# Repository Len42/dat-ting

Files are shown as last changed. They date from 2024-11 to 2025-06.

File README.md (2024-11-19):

# dat ting

_Multi-function Eurorack module inspired by [dis ting](https://www.expert-sleepers.co.uk/disting.html)_

**dat ting** is a digital multi-function 10 HP Eurorack module using a [Daisy Seed](https://electro-smith.com/products/daisy-seed). Part of my [homebrew Eurorack synthesizer](https://lenp.net/synth/).

[See here](https://lenp.net/synth/dat-ting/) for more info.

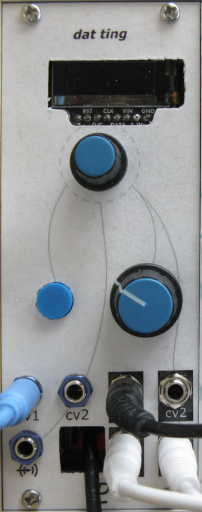
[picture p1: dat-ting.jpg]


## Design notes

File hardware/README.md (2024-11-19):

# dat ting

**dat ting** is a digital multi-function 10 HP Eurorack module using a [Daisy Seed](https://electro-smith.com/products/daisy-seed).

[See here](https://lenp.net/synth/dat-ting/hardware.html) for more info.

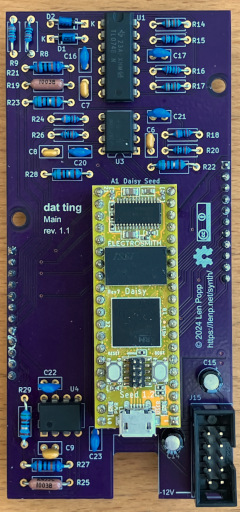
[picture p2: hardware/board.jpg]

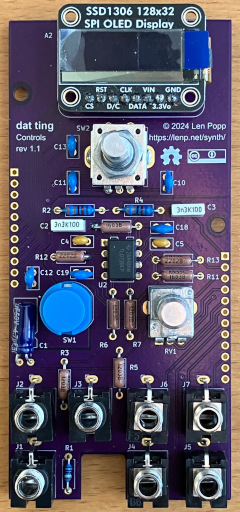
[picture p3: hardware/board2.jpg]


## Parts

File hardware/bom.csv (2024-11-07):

Reference | Qty | Value | Value2 | Note | Description | Datasheet | Manufacturer | ManufacturerPartNum | Distributor | DistributorPartNum | DistributorPartLink | Distributor2 | DistributorPartNum2 | DistributorPartLink2 | Distributor3 | DistributorPartNum3 | DistributorPartLink3
A1 | 1 | Daisy_Seed |  |  | Electrosmith Daisy Seed DSP Microcontroller Module ARM Cortex-M7 | https://daisy.nyc3.cdn.digitaloceanspaces.com/products/seed/Daisy_Seed_datasheet.pdf | Electrosmith |  | Electrosmith |  | https://electro-smith.com/products/daisy-seed | Thonk | PCB_Daisy_Seed | https://www.thonk.co.uk/shop/electrosmith-daisy-seed/
A2 | 1 | OLED_SPI_128x32 |  |  | OLED display module 128x32 pixels SPI with header | https://learn.adafruit.com/monochrome-oled-breakouts | Adafruit | 661 | Adafruit | 661 | https://www.adafruit.com/product/661
A3 | 1 | Cable_Eurorack_10 |  | Length as required | Eurorack 16-10 pin power cable |  |  |  | Thonk |  | https://www.thonk.co.uk/shop/eurorack-power-cables/ | SynthCube |  | https://synthcube.com/cart/eurorack-ribbon-power-cables | Modular Addict |  | https://modularaddict.com/parts/eurorack-power-cables-1
A4 | 1 | Micro USB Adapter 90deg |  |  | Micro USB adapter/cable, 90 deg. |  | StarTech |  | Amazon |  | https://www.amazon.ca/dp/B00EANUQ5M
C1 | 1 | 4U7 |  |  | Capacitor - Non-polarized Electrolytic | https://www.mouser.ca/datasheet/2/315/ABA0000C1053-947510.pdf | Panasonic | ECE-A1HN4R7U | Mouser | 667-ECE-A1HN4R7U | https://www.mouser.ca/ProductDetail/667-ECE-A1HN4R7U
C2 C3 | 2 | 3N3 |  |  | Capacitor - Film | https://www.mouser.ca/datasheet/2/447/KEM_F3101_R82-3316969.pdf | KEMET | R82EC1330AA50K | Mouser | 80-R82EC1330AA50K | https://www.mouser.ca/ProductDetail/KEMET/R82EC1330AA50K?qs=Jv4FAWB%252B0HZwlJiQ4ts8bA%3D%3D
C4 C5 | 2 | 5P6 | C0G/NP0 |  | Capacitor - Ceramic | https://www.mouser.ca/datasheet/2/212/KEM_C1049_GOLDMAX_C0G-1102120.pdf | KEMET | C315C569D1G5TA | Mouser | 80-C315C569D1G | https://www.mouser.ca/ProductDetail/?qs=qe%2F8UmbcoTBh6wC284cfAA%3D%3D
C6 C7 C8 C9 | 4 | 47P | C0G/NP0 |  | Capacitor - Ceramic | https://www.vishay.com/docs/45171/kseries.pdf | Vishay | K470K15C0GH53L2 | Mouser | 594-K470K15C0GH53L2 | https://www.mouser.ca/ProductDetail/Vishay-BC-Components/K470K15C0GH53L2?qs=vmM6vcLFxxH%252BnUnXm2ihfA%3D%3D
C10 C11 C12 C13 C16 C17 C18 C19 C20 C21 C22 C23 | 12 | 100N |  | IC decoupling | -- mixed values -- | https://product.tdk.com/system/files/dam/doc/product/capacitor/ceramic/lead-mlcc/catalog/leadmlcc_halogenfree_fg_en.pdf | TDK | FG18X7R1H104KNT06 | Mouser | 810-FG18X7R1H104KNT6 | https://www.mouser.ca/ProductDetail/810-FG18X7R1H104KNT6
C14 C15 | 2 | 10U | 35 VDC | 12 V decoupling | Capacitor - Electrolytic - 12 V decoupling | https://www.mouser.ca/datasheet/2/315/ABA0000C1059-947582.pdf | Panasonic | ECE-A1VKS100I | Mouser | 667-ECE-A1VKS100I | https://www.mouser.ca/ProductDetail/667-ECE-A1VKS100I | Thonk | Group_Eurorack_DIY_Essential | https://www.thonk.co.uk/shop/eurorack-diy-essentials/
D1 D2 | 2 | 1N5711 |  |  | Schottky signal diode | https://www.mouser.ca/datasheet/2/389/cd00000759-1795802.pdf | STMicroelectronics | 1N5711 | Mouser | 511-1N5711 | https://www.mouser.ca/ProductDetail/STMicroelectronics/1N5711?qs=FITO%2F%2FQgYDnH7pJ7rS2FRA%3D%3D
H1 H5 H6 H10 | 4 | HW_Screw_M3x0.50x6 |  |  | Machine screw, M3x0.50x6 | ~
H3 H8 | 2 | HW_Standoff_F-F_11mm_M3x0.50 |  |  | Standoff, 11mm, female-female, M3x0.50 | https://www.thonk.co.uk/wp-content/uploads/2018/05/standoff-datasheet.pdf | Ettinger | 05.03.111 | Thonk | Mech_11mm_Standoff_(x10) | https://www.thonk.co.uk/shop/standoffs/ | Mouser | 710-970110321 | https://www.mouser.ca/ProductDetail/Wurth-Elektronik/970110321?qs=wr8lucFkNMUs0IWSCWTB3w%3D%3D | Mouser | 144-MTS-11 | https://www.mouser.ca/ProductDetail/144-MTS-11
J1 J2 J3 J4 J5 J6 J7 | 7 | WQP-PJ398 |  |  | Audio Jack, 2 Poles (Mono / TS), Switched T Pole (Normalling), QingPu / Thonkiconn | http://www.qingpu-electronics.com/en/products/WQP-PJ398SM-362.html | QingPu / Thonk | PJ398SM / WQP518MA | Thonk | PJ398SM | https://www.thonk.co.uk/shop/thonkiconn/ | SynthCube | WQP518MA | https://synthcube.com/cart/3-5mm-euro-jacks | Adafruit | 4031 | https://www.adafruit.com/product/4031
J8 J9 | 2 | Conn_01x20 |  |  | Pin socket connector, single row, 01x08 | https://cdn-shop.adafruit.com/datasheets/00548.pdf |  |  | Adafruit | 598 | https://www.adafruit.com/product/598 | Mouser | 710-61303211821 | https://www.mouser.ca/ProductDetail/Wurth-Elektronik/61303211821?qs=ZtY9WdtwX55M%2FH%2FSrHZ9xA%3D%3D
J10 | 1 | Conn_01x08 |  | OLED module needs a header connector with 8mm pins |  | https://www.amphenol-icc.com/media/wysiwyg/files/documentation/datasheet/boardwiretoboard/bwb_econostik_254headers.pdf | Amphenol FCI | 10129378-936003BLF | Mouser | 649-1012937893603BLF | https://www.mouser.ca/ProductDetail/Amphenol-FCI/10129378-936003BLF?qs=0lQeLiL1qyY4DvLV7KWmVQ%3D%3D
J11 | 1 | Conn_Front_Left |  |  | Generic connector, single row, 01x11, script generated (kicad-library-utils/schlib/autogen/connector/) | https://cdn-shop.adafruit.com/datasheets/00548.pdf |  |  | Adafruit | 598 | https://www.adafruit.com/product/598 | Mouser | 710-61303211821 | https://www.mouser.ca/ProductDetail/Wurth-Elektronik/61303211821?qs=ZtY9WdtwX55M%2FH%2FSrHZ9xA%3D%3D
J12 | 1 | Conn_Back_Right |  |  | Generic connector, single row, 01x11, script generated (kicad-library-utils/schlib/autogen/connector/) | https://www.amphenol-icc.com/media/wysiwyg/files/documentation/datasheet/boardwiretoboard/bwb_econostik_254headers.pdf |  |  | Adafruit | 392 | https://www.adafruit.com/product/392 | Mouser | 649-1012937893601BLF | https://www.mouser.ca/ProductDetail/649-1012937893601BLF
J13 | 1 | Conn_Front_Right |  |  | Generic connector, single row, 01x12, script generated (kicad-library-utils/schlib/autogen/connector/) | https://cdn-shop.adafruit.com/datasheets/00548.pdf |  |  | Adafruit | 598 | https://www.adafruit.com/product/598 | Mouser | 710-61303211821 | https://www.mouser.ca/ProductDetail/Wurth-Elektronik/61303211821?qs=ZtY9WdtwX55M%2FH%2FSrHZ9xA%3D%3D
J14 | 1 | Conn_Back_Left |  |  | Generic connector, single row, 01x12, script generated (kicad-library-utils/schlib/autogen/connector/) | https://www.amphenol-icc.com/media/wysiwyg/files/documentation/datasheet/boardwiretoboard/bwb_econostik_254headers.pdf |  |  | Adafruit | 392 | https://www.adafruit.com/product/392 | Mouser | 649-1012937893601BLF | https://www.mouser.ca/ProductDetail/649-1012937893601BLF
J15 | 1 | Conn_Eurorack_10 |  |  | Eurorack 10-pin board power connector | https://www.mouser.ca/datasheet/2/445/61201021621-1717731.pdf | Wurth Elektronik | 61201021621 | Mouser | 710-61201021621 | https://www.mouser.ca/ProductDetail/Wurth-Elektronik/61201021621 | Thonk |  | https://www.thonk.co.uk/shop/eurorack-diy-essentials/
R1 | 1 | 1M | 1%, 1/6 W |  | Resistor | https://www.mouser.ca/datasheet/2/447/YAGEO_MFR_datasheet_2023v3-3324391.pdf | YAGEO | MFR-12FTF52-1M | Mouser | 603-MFR-12FTF52-1M | https://www.mouser.ca/ProductDetail/YAGEO/MFR-12FTF52-1M?qs=oAGoVhmvjhw%2F%2F4epxEjLtQ%3D%3D
R2 R4 | 2 | 33K | 0.1%, 0.1W |  | Resistor | https://www.mouser.ca/datasheet/2/447/Yageo_LR_MFP_1-1947926.pdf | YAGEO | MFP-25BRD52-33K | Mouser | 603-MFP-25BRD52-33K | https://www.mouser.ca/ProductDetail/YAGEO/MFP-25BRD52-33K?qs=wcZjbqjoJeglQC7yt5ggnA%3D%3D
R3 R5 R6 R7 | 4 | 120K | 0.1%, 0.1W | Use 1 x 240K (0.1%) in place of 2 x 120K if available | Resistor | https://www.vishay.com/docs/31027/cmfmil.pdf | Vishay | RN55E1203BRE6 | Mouser | 71-RN55E1203BTR | https://www.mouser.ca/ProductDetail/Vishay-Dale/RN55E1203BRE6?qs=%2FtbKA%252B9EriDenPWbNFO2eA%3D%3D
R8 R20 R26 | 3 | 100K | 1%, 1/6 W |  | Resistor | https://www.mouser.ca/datasheet/2/447/YAGEO_MFR_datasheet_2023v3-3324391.pdf | YAGEO | MFR-12FRF52-100K | Mouser | 603-MFR-12FRF52100K | https://www.mouser.ca/ProductDetail/YAGEO/MFR-12FRF52-100K?qs=19cKSROHwrAZsaNp2yj6EQ%3D%3D
R9 | 1 | 33K | 1%, 1/6 W |  | Resistor | https://www.mouser.ca/datasheet/2/447/YAGEO_MFR_datasheet_2023v3-3324391.pdf | YAGEO | MFR-12FTF52-33K | Mouser | 603-MFR-12FTF52-33K | https://www.mouser.ca/ProductDetail/YAGEO/MFR-12FTF52-33K?qs=oAGoVhmvjhwEbngQR0rfoQ%3D%3D
R10 R11 | 2 | 160K | 0.1%, 0.1W |  | Resistor | https://www.vishay.com/docs/31027/cmfmil.pdf | Vishay | RN55C1603BRE6 | Mouser | 71-RN55C1603BTR | https://www.mouser.ca/ProductDetail/Vishay-Dale/RN55C1603BRE6?qs=F7UM01vn%252BgPuoQxB287Mtg%3D%3D
R12 R13 | 2 | 22K | 0.1%, 0.1W |  | Resistor | https://www.vishay.com/docs/31027/cmfmil.pdf | Vishay | RN55C2202BRE6 | Mouser | 71-RN55C2202BTR | https://www.mouser.ca/ProductDetail/Vishay-Dale/RN55C2202BRE6?qs=hyU79xNWhW1PD%252BZ%252BPS2bwA%3D%3D
R14 R17 | 2 | 130K | 1%, 1/6 W |  | Resistor | https://www.mouser.ca/datasheet/2/447/YAGEO_MFR_datasheet_2023v3-3324391.pdf | YAGEO | MFR-12FTF52-130K | Mouser | 603-MFR-12FTF52-130K | https://www.mouser.ca/ProductDetail/YAGEO/MFR-12FTF52-130K?qs=oAGoVhmvjhwGhRGh%2FUMCLQ%3D%3D
R15 R16 | 2 | 20K | 1%, 1/6 W |  | Resistor | https://www.mouser.ca/datasheet/2/447/YAGEO_MFR_datasheet_2023v3-3324391.pdf | YAGEO | MFR-12FTF52-20K | Mouser | 603-MFR-12FTF52-20K | https://www.mouser.ca/ProductDetail/YAGEO/MFR-12FTF52-20K?qs=oAGoVhmvjhx30ELEgu5Hag%3D%3D
R18 R24 | 2 | 36K | 1%, 1/6 W |  | Resistor | https://www.mouser.ca/datasheet/2/447/YAGEO_MFR_datasheet_2023v3-3324391.pdf | YAGEO | MFR-12FTF52-36K | Mouser | 603-MFR-12FTF52-36K | https://www.mouser.ca/ProductDetail/YAGEO/MFR-12FTF52-36K?qs=oAGoVhmvjhyIq6EO5blb%252BQ%3D%3D
R19 R25 | 2 | 100K | 0.1%, 0.1W |  | Resistor | https://www.vishay.com/docs/31027/cmfmil.pdf | Vishay | RN55C1003BRE6 | Mouser | 71-RN55C-B-100K/R | https://www.mouser.ca/ProductDetail/Vishay-Dale/RN55C1003BRE6?qs=t6F1uLNKm5H%2FV%2FsNi0%252BkXQ%3D%3D
R21 R27 | 2 | 200K | 0.1%, 0.1W |  | Resistor | https://www.mouser.ca/datasheet/2/447/yago_s_a0000107546_1-2286378.pdf | YAGEO | MFP-25BRD52-200K | Mouser | 603-MFP-25BRD52-200K | https://www.mouser.ca/ProductDetail/YAGEO/MFP-25BRD52-200K?qs=i6Zrxxj4WsPiDiIa6%252BsVcg%3D%3D
R22 R23 R28 R29 | 4 | 51R | 1%, 1/4 W | Output limiting | Resistor | https://www.mouser.ca/datasheet/2/447/Yageo_LR_MFR_1-1714151.pdf | YAGEO | MFR-25FBF52-51R | Mouser | 603-MFR-25FBF52-51R | https://www.mouser.ca/ProductDetail/?qs=oAGoVhmvjhzVx2bdEH1TLQ%3D%3D
RV1 | 1 | 100K | LIN |  | Potentiometer | https://www.mouser.ca/datasheet/2/13/alpha_taiwan_08192019_RD901F-40-15R1-B(resistance_-1627810.pdf | Alpha | RD901F-* | Thonk | Group_Pot_Alpha_6.35mm | https://www.thonk.co.uk/shop/alpha-9mm-pots/ | Mouser | 311-1940F-* | https://www.mouser.ca/c/passive-components/potentiometers-trimmers-rheostats/potentiometers/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 | SynthCube | 9MMALPHAPOTMSTR | https://synthcube.com/cart/alpha-9mm-potentiometer-right-angle-pcb-mount-6-35mm-round-shaft
SW1 | 1 | C&K_D6R |  |  | Push button switch, C&K D6R series | https://www.mouser.ca/datasheet/2/60/d6-1382571.pdf | C&K | D6R60F1LFS | Mouser | 611-D6R60F1LFS | https://www.mouser.ca/ProductDetail/CK/D6R60F1LFS?qs=sb%252But3Lm4x0VR1WI58%252Bz2w%3D%3D
SW2 | 1 | PEC11R |  |  | Rotary encoder, incremental quadrate outputs, with switch | https://www.mouser.ca/datasheet/2/54/PEC11R-777457.pdf | Bourns | PEC11R-4220F-S0024 | Mouser | 652-PEC11R-4220F-S24 | https://www.mouser.ca/ProductDetail/Bourns/PEC11R-4220F-S0024?qs=Zq5ylnUbLm6NGsQdib%2Ffbw%3D%3D
U1 | 1 | TL074 |  |  | Quad Low-Noise JFET-Input Operational Amplifiers, DIP-14/SOIC-14 | http://www.ti.com/lit/ds/symlink/tl071.pdf | Texas Instruments | TL074BCN | Mouser | 595-TL074BCN | https://www.mouser.ca/ProductDetail/?qs=vxEfx8VrU7BHurOY5iQdiA%3D%3D
U2 U3 | 2 | TL072 |  |  | Dual Low-Noise JFET-Input Operational Amplifiers, DIP-8/SOIC-8 | https://www.ti.com/lit/ds/symlink/tl072b.pdf?ts=1628812694194 | Texas Instruments | TL072BCP | Mouser | 595-TL072BCP | https://www.mouser.ca/ProductDetail/Texas-Instruments/TL072BCP?qs=p6YqzpSxLIxmo8AyZLsP4g%3D%3D
U4 | 1 | TL071 |  |  | Single Low-Noise JFET-Input Operational Amplifiers, DIP-8/SOIC-8 | http://www.ti.com/lit/ds/symlink/tl071.pdf | Texas Instruments | TL071BCP | Digi-Key | 296-34258-5-ND | https://www.digikey.ca/en/products/detail/texas-instruments/TL071BCP/1674458 | Mouser | 595-TL071IPE4 | https://www.mouser.ca/ProductDetail/Texas-Instruments/TL071IPE4?qs=odmYgEirbwzwe%252BIRDerVMA%3D%3D

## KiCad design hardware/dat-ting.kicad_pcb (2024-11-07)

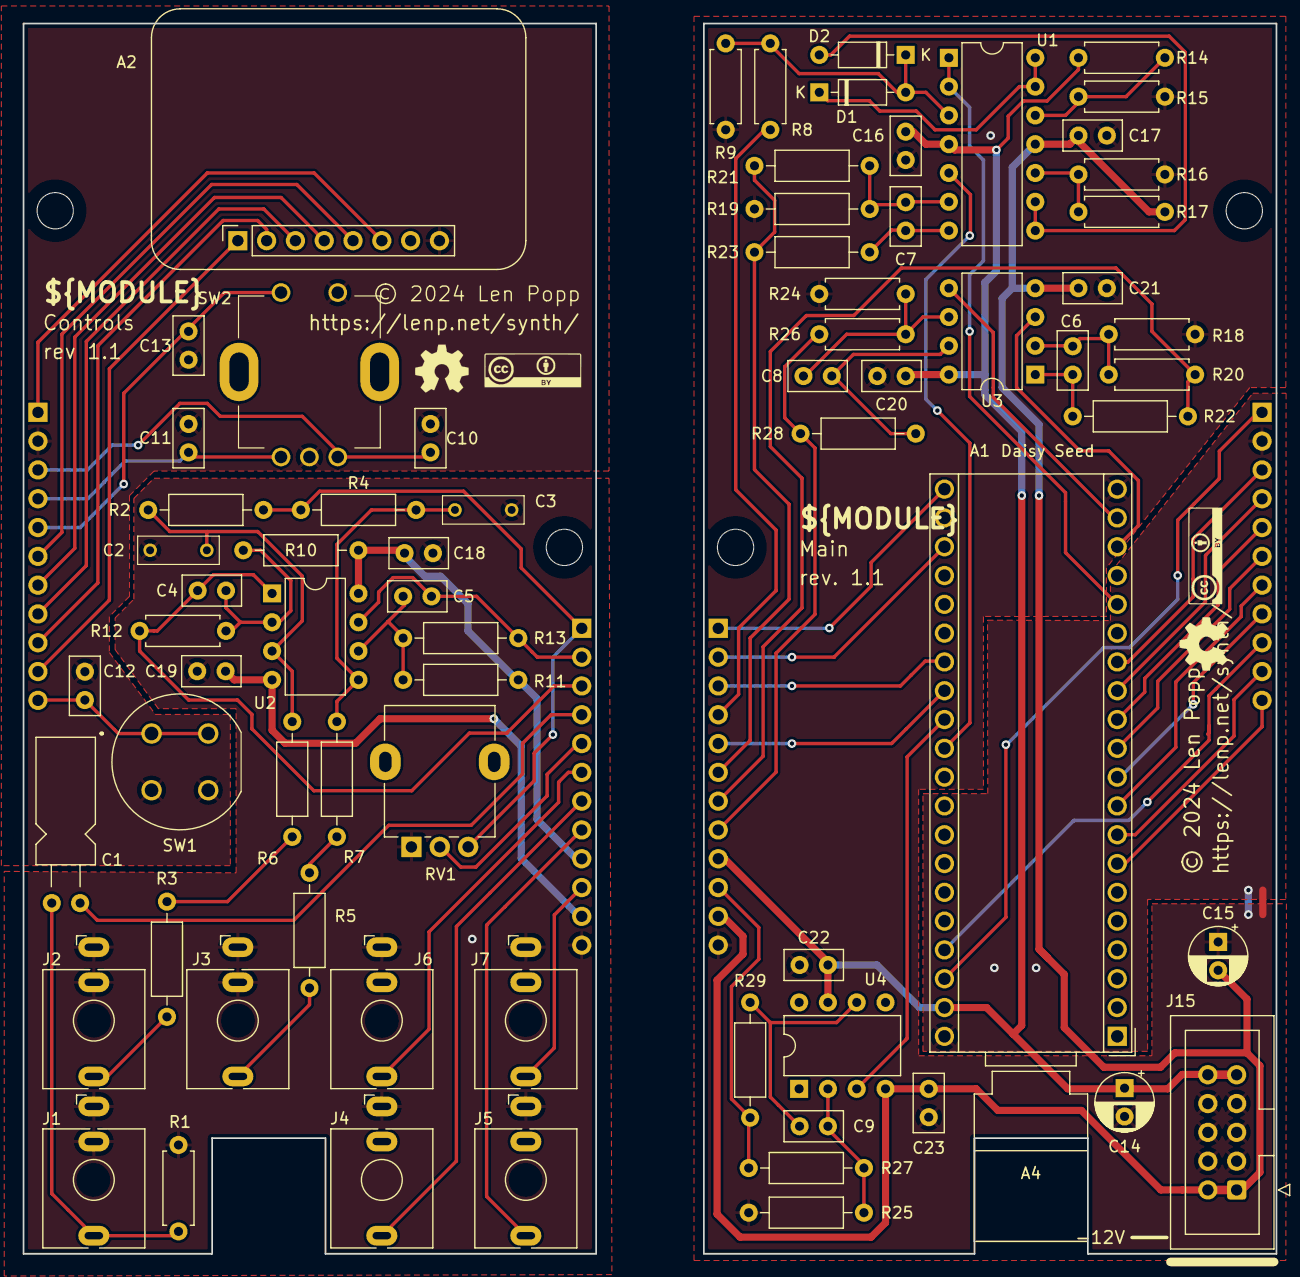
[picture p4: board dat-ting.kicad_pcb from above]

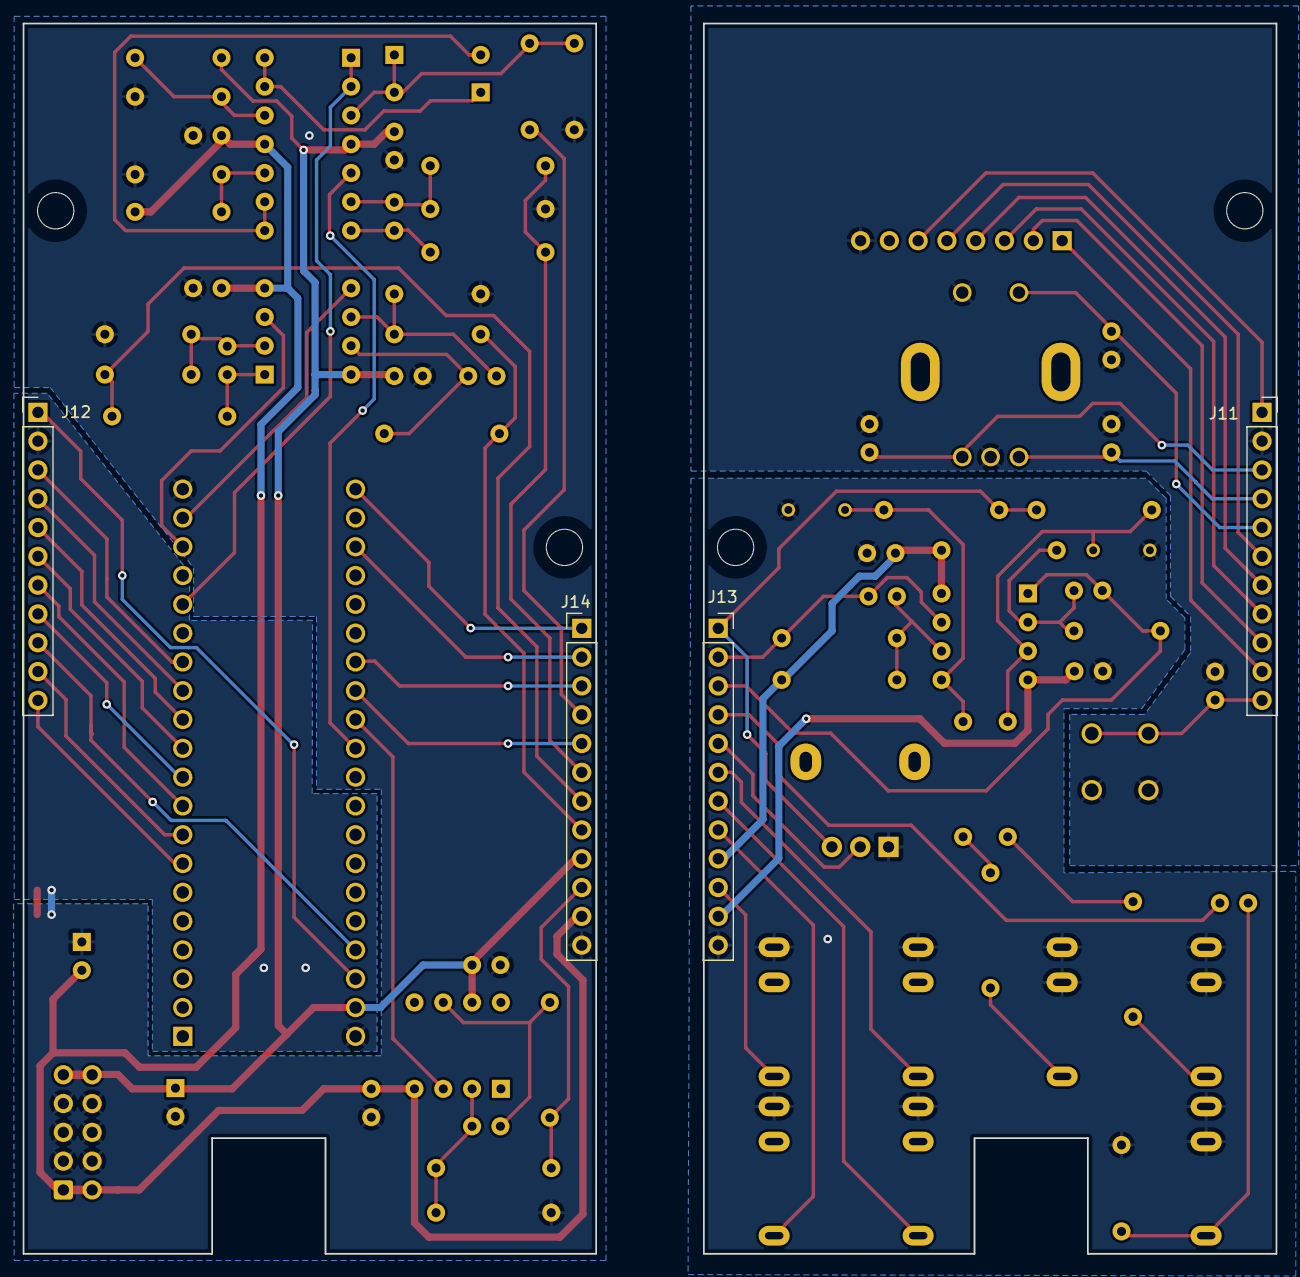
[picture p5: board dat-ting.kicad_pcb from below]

Board: 2 copper layers, 110.5 x 108.5 mm, 84 parts (4 on the bottom side), 49 nets.

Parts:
A1: Daisy_Seed; Module_Daisy_Seed
A2: OLED_SPI_128x32; OLED_SPI_128x32_0.91in_NoHoles
A4: Micro USB Adapter 90deg; USB-Micro-Adapter-90-Outline
C1: 4U7; C_Radial_L11.0mm_D5.0mm_P2.50mm_Horiz
C2, C3: 3N3; C_Rect_Kemet_L7.2mm_W2.5mm_P5mm
C4, C5: 5P6; C_Disc_D5.0mm_W2.5mm_P2.50mm
C6, C7, C8, C9: 47P; C_Disc_D5.0mm_W2.5mm_P2.50mm
C10, C11, C12, C13, C16, C17, C18, C19, C20, C21, C22, C23: 100N; C_Disc_D5.0mm_W2.5mm_P2.50mm
C14, C15: 10U; CP_Radial_D5.0mm_P2.50mm
D1, D2: 1N5711; D_DO-35_SOD27_P7.62mm_Horizontal
G1, G2: LOGO; Logo_CC_BY
G3, G4: LOGO; Logo_OSHW
H2, H4, H7, H9: MountingHole_M3; MountingHole_PCB_3.2mm_M3
J1, J2, J3, J4, J5, J6, J7: WQP-PJ398; Jack_3.5mm_QingPu_WQP-PJ398SM_Vertical
J11: Conn_Front_Left; PinSocket_1x11_P2.54mm_Vertical
J12: Conn_Back_Right; PinHeader_1x11_P2.54mm_Vertical
J13: Conn_Front_Right; PinSocket_1x12_P2.54mm_Vertical
J14: Conn_Back_Left; PinHeader_1x12_P2.54mm_Vertical
J15: Conn_Eurorack_10; IDC-Header-Eurorack-10-TH
R1: 1M; R_Axial_DIN0207_L6.3mm_D2.5mm_P7.62mm_Horizontal
R2, R4: 33K; R_Axial_DIN0207_L6.3mm_D2.5mm_P10.16mm_Horizontal
R3, R5, R6, R7: 120K; R_Axial_DIN0207_L6.3mm_D2.5mm_P10.16mm_Horizontal
R8, R20, R26: 100K; R_Axial_DIN0207_L6.3mm_D2.5mm_P7.62mm_Horizontal
R9: 33K; R_Axial_DIN0207_L6.3mm_D2.5mm_P7.62mm_Horizontal
R10, R11: 160K; R_Axial_DIN0207_L6.3mm_D2.5mm_P10.16mm_Horizontal
R12: 22K; R_Axial_DIN0207_L6.3mm_D2.5mm_P7.62mm_Horizontal
R13: 22K; R_Axial_DIN0207_L6.3mm_D2.5mm_P10.16mm_Horizontal
R14, R17: 130K; R_Axial_DIN0207_L6.3mm_D2.5mm_P7.62mm_Horizontal
R15, R16: 20K; R_Axial_DIN0207_L6.3mm_D2.5mm_P7.62mm_Horizontal
R18, R24: 36K; R_Axial_DIN0207_L6.3mm_D2.5mm_P7.62mm_Horizontal
R19, R25: 100K; R_Axial_DIN0207_L6.3mm_D2.5mm_P10.16mm_Horizontal
R21, R27: 200K; R_Axial_DIN0207_L6.3mm_D2.5mm_P10.16mm_Horizontal
R22, R23, R28, R29: 51R; R_Axial_DIN0207_L6.3mm_D2.5mm_P10.16mm_Horizontal
RV1: 100K; Potentiometer_Alpha_RD901F-40-00D_Single_Vertical
SW1: C&K_D6R; SW_Push_C&K_D6R
SW2: PEC11R; Encoder_Bourns_PEC11R_Switch
U1: TL074; DIP-14_W7.62mm
U2, U3: TL072; DIP-8_W7.62mm
U4: TL071; DIP-8_W7.62mm

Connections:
+3V3: A1.38 (3v3D), A2.6 (VIN), J11.1, J12.1
+3V3REF: A1.21 (3v3A), J13.1, J14.1, R2.1, R4.1, RV1.3
+12V: A1.39 (VIN), C14.1, C16.1, C18.1, C20.1, C22.1, J13.9, J14.9, J15.9 (+12V), J15.10, R10.2, R11.2, R14.1, U1.4 (V+), U2.8 (V+), U3.8 (V+), U4.7 (V+)
-12V: C15.2, C17.2, C19.2, C21.2, C23.2, J13.11, J14.11, J15.1 (-12V), J15.2, R17.1, U1.11 (V-), U2.4 (V-), U3.4 (V-), U4.4 (V-)
/+CLAMP: D1.1 (K), U1.13 (-), U1.14
/-CLAMP: D2.2 (A), U1.8, U1.9 (-)
ENC-A: A1.13 (D12), C11.1, J11.4, J12.4, SW2.A
ENC-B: A1.14 (D13), C10.1, J11.3, J12.3, SW2.B
ENC-SW: A1.12 (D11), C13.1, J11.5, J12.5, SW2.S1
GND: A1.20 (AGND), A1.40 (GND), A2.8 (GND), C2.2, C3.2, C10.2, C11.2, C12.2, C13.2, C14.2, C15.1, C16.2, C17.1, C18.2, C19.1, C20.2, C21.1, C22.2, C23.1, J1.S, J1.TN, J2.S, J2.TN, J3.S, J3.TN, J4.S, J5.S, J6.S, J7.S, J11.2, J12.2, J13.12, J14.12, J15.3 (GND), J15.4, J15.5 (GND), J15.6, J15.7 (GND), J15.8, R1.2, R9.2, R15.2, R16.2, R18.2, R19.2, R24.2, R25.2, RV1.1, SW1.3, SW1.4, SW2.C, SW2.S2
IN-AUDIO: C1.1, J13.4, J14.4, R8.1
unnamed: C1.2, J1.T, R1.1
unnamed: C6.2, R22.1, U3.1
unnamed: C7.2, R23.1, U1.7
unnamed: C8.2, R28.1, U3.7
unnamed: C9.2, R29.1, U4.6
unnamed: D1.2 (A), D2.1 (K), R8.2, R9.1, U1.3 (+)
unnamed: J2.T, R3.1
unnamed: J3.T, R5.1
unnamed: R3.2, R6.1
unnamed: R5.2, R7.1
unnamed: C7.1, R19.1, R21.1, U1.6 (-)
unnamed: R16.1, R17.2, U1.10 (+)
unnamed: R14.2, R15.1, U1.12 (+)
unnamed: C2.1, R2.2, R6.2, U2.3 (+)
unnamed: C4.1, R10.1, R12.1, U2.2 (-)
unnamed: C3.1, R4.2, R7.2, U2.5 (+)
unnamed: C5.1, R11.1, R13.1, U2.6 (-)
unnamed: C6.1, R18.1, R20.1, U3.2 (-)
unnamed: C8.1, R24.1, R26.1, U3.6 (-)
unnamed: C9.1, R25.1, R27.1, U4.2 (-)
OLED-CD: A1.10 (SPI1_MISO), A2.3 (DC), J11.8, J12.8
OLED-CS: A1.8 (SPI1_NSS), A2.1 (CS), J11.10, J12.10
OLED-DATA: A1.11 (SPI1_MOSI), A2.5 (SDA), J11.6, J12.6
OLED-RST: A1.37 (D30), A2.2 (RESET), J11.9, J12.9
OLED-SCK: A1.9 (SPI1_SCK), A2.4 (SCL), J11.7, J12.7
OUT-AUDIO-L: J4.T, J13.7, J14.7, R20.2, R22.2
OUT-AUDIO-R: J5.T, J13.8, J14.8, R26.2, R28.2
OUT-CV-1: J6.T, J13.6, J14.6, R21.2, R23.2
OUT-CV-2: J7.T, J13.10, J14.10, R27.2, R29.2
SEED-IN-AUDIO: A1.16 (AUDIO_IN_L), U1.1, U1.2 (-)
SEED-IN-CV-1: A1.27 (A5), C4.2, J13.3, J14.3, R12.2, U2.1
SEED-IN-CV-2: A1.23 (A1), C5.2, J13.2, J14.2, R13.2, U2.7
SEED-IN-CV-POT: A1.28 (A6), J13.5, J14.5, RV1.2
SEED-IN-SW: A1.7 (D6), C12.1, J11.11, J12.11, SW1.1, SW1.2
SEED-OUT-AUDIO-L: A1.18 (AUDIO_OUT_L), U3.3 (+)
SEED-OUT-AUDIO-R: A1.19 (AUDIO_OUT_R), U3.5 (+)
SEED-OUT-CV-1: A1.30 (DAC1_OUT1), U1.5 (+)
SEED-OUT-CV-2: A1.29 (DAC1_OUT2), U4.3 (+)

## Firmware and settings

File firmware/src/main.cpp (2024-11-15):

#include <algorithm>
#include <array>
#include <atomic>
#include <cmath>
#include <limits>
#include <optional>
#include <ranges>
#include <span>
#include <string_view>
using namespace std::string_view_literals;
#include <utility>

#include "version.h"
#pragma message "Building " PROG_NAME " version " BUILD_VERSION
#include "sysutils.h"

#include "daisy_seed2.h"
#include "daisysp.h"
#include "tasks.h"
#include "ringbuf.h"
#include "datatable.h"
#include "lookup.h"

// Set the type of hardware being used.
enum class HWType { Prototype, Module };
#ifndef HW_TYPE
#define HW_TYPE Prototype
#endif
#pragma message "Building for " sym_to_string(HW_TYPE) " hardware"

#include "PinDefs.h"
#include "CVIn.h"
#include "CVOut.h"

#include "Hardware.h"

#include "Graphics.h"
#include "Animation.h"
#include "Program.h"
#include "ProgList.h"
#include "MiscTasks.h"
#include "UITask.h"

/// @brief The list of tasks to execute
/// @details Excludes the AudioCallback and related timing-critical tasks
static constexpr tasks::TaskList<
    AnimationTask
    ,UIImpl::UI<ProgramList, programs>::Task
    //,BlinkTask
    //,ButtonLedTask
    //,GateLedTask
    //,AdcOutputTask
    //,AdcCalibrateTask
    //,SampleRateTask
    //,ProgReverb::DebugTask
> taskList;

int main()
{
    // Initialize the hardware
    HW::Init();

    // Start audio processing
    HW::StartProcessing(ProgramList::ProcessingCallback);

    // Start a Program running
    // TODO: Get the previously-running program from saved settings
    programs.RunProgram(programs.GetList().front());

    // Run all tasks, forever.
    taskList.initAll();
    for (;;) {
        taskList.runAll();
    }

    return 0;
}

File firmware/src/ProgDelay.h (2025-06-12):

#pragma once

/// @brief Maximum delay time in seconds
static constexpr float maxDelaySecs = 10;

/// @brief Maximum delay time in samples
static constexpr size_t maxDelaySamples = size_t(maxDelaySecs * HW::sampleRate);

/// @brief Specialized delay-line type
using DelayLine = daisysp::DelayLine<float, maxDelaySamples>;

// BUG: DelayLine variables should be static data members in ProgDelay but then
// it cannot be stored in SDRAM (DSY_SDRAM_BSS does nothing in that case).

/// @brief Delay line for regular delay
static DelayLine DSY_SDRAM_BSS delayLine1;

/// @brief Delay line for ping-pong delay
static DelayLine DSY_SDRAM_BSS delayLine2;

/// @brief Delay/echo @ref Program
/// @details Implements normal and ping-pong delay. Various parameters can be set
/// by the potentiometer or CV inputs. Pushbutton is used for tap tempo.
class ProgDelay : public Program
{
    using this_t = ProgDelay;

    // Declare the configurable parameters of this program
    #define PARAM_VALUES(ITEM) \
        ITEM(Normal, "Normal") \
        ITEM(PingPong, "Ping-pong")
    DECL_PARAM_VALUES(Mode)
    #undef PARAM_VALUES
    #define PARAM_VALUES(ITEM) \
        ITEM(Div31, "3:1") \
        ITEM(Div21, "2:1") \
        ITEM(Div32, "3:2") \
        ITEM(Div11, "1:1") \
        ITEM(Div23, "2:3")
    DECL_PARAM_VALUES(TapDiv)
    #undef PARAM_VALUES
    #define PROG_PARAMS(ITEM) \
        PARAM_NUM(ITEM, Mode, "Delay mode", unsigned(Mode::Normal)) \
        PARAM_CVSOURCE(ITEM, DelayControl, "Delay control", Pot) \
        PARAM_CVSOURCE(ITEM, FeedbackControl, "Feedback control", Fixed) \
        PARAM_CVSOURCE(ITEM, MixControl, "Mix control", Fixed) \
        PARAM_CVSOURCE(ITEM, ModRateControl, "Mod rate control", Fixed) \
        PARAM_CVSOURCE(ITEM, ModDepthControl, "Mod depth ctrl.", Fixed) \
        PARAM_NUM(ITEM, TapDiv, "Tap division", unsigned(TapDiv::Div11))
    DECL_PROG_PARAMS
    #undef PROG_PARAMS

public:
    constexpr std::string_view GetName() const override { return "Delay"sv; }

    void Init() override
    {
        theProgram = this; // DEBUG

        delayLine1.Init();
        delayLine2.Init();
        SetDelayCv(delaySave, 0);
        SetFeedbackAmount(feedbackAmount);

        mix.Init(daisysp::CROSSFADE_CPOW);
        SetMixLevel(effectMixLevel);

        lfoMod.Init(HW::sampleRate);
        lfoMod.SetWaveform(daisysp::Oscillator::WAVE_SIN);
        SetModRateHz(delayModRate);
        SetModDepth(delayModDepth);
    }

    void Process(ProcessArgs& args) override
    {
        // LFO and CV input are processed once per callback, not once per sample
        ReadCv(args);

        // Tap tempo setting
        bool tapped = false;
        if (args.GateOn(HW::CVIn::Button)) {
            HandleTap();
            tapped = true;
        }

        // Delay processing
        for (auto&& [in, out] : std::views::zip(args.inbuf, args.outbuf)) {
            float input = in.left;
            float delayed = delayLine1.Read();
            float feedback = delayed * feedbackAmount;
            out.left = mix.Process(input, delayed);
            if (GetMode() == unsigned(Mode::PingPong)) {
                // Ping-pong stereo delay: Two delay lines, one for each channel
                delayLine2.Write(feedback);
                delayed = delayLine2.Read();
                feedback = delayed * feedbackAmount;
                out.right = mix.Process(input, delayed);
            } else {
                // Normal delay: Single delay line output on both channels
                out.right = out.left;
            }
            delayLine1.Write(feedback + input);
        }

        // Update the animation display with the last-calculated result
        auto animIn = args.inbuf.back();
        auto animOut = args.outbuf.back();
        animation.SetAmplitude(animOut.left,
                               tapped ? 0.25f : animIn.left,
                               animOut.right);
    }

    Animation* GetAnimation() const override { return &animation; }

protected:
    /// @brief Update various CV-controlled parameters according to settings
    /// @details This is called once per Process callback, not once per audio sample.
    /// In addition to the input CVs, this also handles the software LFO.
    /// @param args 
    void ReadCv(const ProcessArgs& args)
    {
        // Modulation LFO
        HW::CVIn::GetUnipolarExp(GetModRateControl())
            .and_then([this](float val) { SetModRateCv(val); return emptyOpt; });
        HW::CVIn::GetUnipolar(GetModDepthControl())
            .and_then([this](float val) { SetModDepth(val); return emptyOpt; });
        float modVal = lfoMod.Process();

        // CV inputs
        // Must always call SetDelayCv even if GetUnipolarExp() returns nothing
        // because modVal must always be processed.
        auto cv = HW::CVIn::GetUnipolarExp(GetDelayControl());
        SetDelayCv(cv, modVal);
        HW::CVIn::GetUnipolar(GetFeedbackControl())
            .and_then([this](float val) { SetFeedbackAmount(val); return emptyOpt; });
        HW::CVIn::GetUnipolar(GetMixControl())
            .and_then([this](float val) { SetMixLevel(val); return emptyOpt; });
    }

    float delaySamples = 10000; ///< Delay time in samples

    float delaySave = 0.05;     ///< Last-used delay CV value, used to detect changes

    RunningAverage<float, 48> avgDelay; ///< Delay CV smoother-outer to avoid ugliness

    /// @brief Return the delay time in samples
    /// @return 
    float GetDelaySamples() const { return delaySamples; }

    /// @brief Set the delay time from a unipolar CV value, with modulation
    /// @param delay optional delay CV value
    /// @param modVal delay modulation value
    void SetDelayCv(std::optional<float> delay, float modVal)
    {
        // Update the current delay value, only if given and only if it has
        // changed sufficiently.
        if (delay) {
            static constexpr float minChange = 0.0001;
            delay = avgDelay.update(*delay);
            if (isDifferent(*delay, delaySave, minChange)) {
                delaySave = *delay;
            }
        }
        float delaySecs = delaySave * maxDelaySecs;
        // Always update the delay because modVal is always changing
        delaySecs += modVal;
        SetDelaySecs(delaySecs);
    }

    /// @brief Set the delay time in seconds
    /// @param delaySecs 
    void SetDelaySecs(float delaySecs) { SetDelaySamples(delaySecs * HW::sampleRate); }

    /// @brief Set the delay time in samples
    /// @param samples 
    void SetDelaySamples(float samples)
    {
        delaySamples = samples;
        delayLine1.SetDelay(samples);
        delayLine2.SetDelay(samples);
    }

    float delayModRate = 5;     ///< Delay time modulation rate
    
    daisysp::Oscillator lfoMod; ///< LFO for delay time modulation

    /// @brief Return the delay time modulation rate in Hertz
    /// @return 
    float GetModRateHz() const { return delayModRate; }
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

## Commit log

2024-11-07 Cleaned-up copy of the current dev repo
    [bom.csv, dat-ting-2.kicad_sch, dat-ting.kicad_pcb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]
2024-11-09 hardware: add schematic.pdf, update PCB photos
2024-11-18 firmware: Fix a UI bug
    [UITask.h]
2024-11-19 firmware: Variable-shape VCO: pitch modulation from CV2
2024-12-05 firmware: Misc changes: - Rename some functions for consistency - Fix a gate-off bug - add midValue() function
    [CVIn.h]

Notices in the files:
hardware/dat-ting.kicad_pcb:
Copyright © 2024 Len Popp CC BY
